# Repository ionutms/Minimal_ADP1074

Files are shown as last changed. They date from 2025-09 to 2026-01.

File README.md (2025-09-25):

# Minimal_ADP1074

## Overview

This repository contains a minimal KiCad design project for the Analog Devices ADP1074, a current mode synchronous flyback controller with iCoupler-isolated feedback. The project includes schematic designs and PCB layout files for implementing this isolated power supply controller.

## Disclaimer

> [!NOTE]
> This project is provided "as is" and without any warranty, express or implied. For more details, please see the [LICENSE](LICENSE) file.

## About the ADP1074

The ADP1074 from Analog Devices is a current mode synchronous flyback controller with integrated iCoupler technology for isolated feedback. It is designed for high-efficiency, compact isolated DC-to-DC converters.

Key features include:

- **Integrated iCoupler Technology:** Provides isolated feedback without the need for an optocoupler, improving reliability and performance.
- **Current Mode Control:** Offers excellent line and load transient response.
- **Synchronous Rectification:** Improves efficiency by replacing the secondary-side diode with a MOSFET.
- **Programmable Frequency:** The switching frequency can be adjusted to optimize for size or efficiency.
- **Protection Features:** Includes overcurrent protection (OCP), overvoltage protection (OVP), and thermal shutdown.
- **Wide Input Voltage Range:** Supports a broad range of input voltages, making it suitable for various applications.
- **Package:** Available in a 24-lead LFCSP package.

## Project Structure

```
minimal_adp1074/
├── minimal_adp1074.kicad_pro       # Project configuration file
├── minimal_adp1074.kicad_sch       # Main schematic file
├── minimal_adp1074.kicad_pcb       # PCB layout file
├── fp-lib-table                    # Footprint library table
├── sym-lib-table                   # Symbol library table
├── docs/                           # Documentation files
│   ├── bom/                        # Bill of Materials
│   │   └── minimal_adp1074_ibom.html # Interactive BOM file
│   ├── pictures/                   # Images and photos
│   │   ├── 1_minimal_adp1074_side.png
│   │   ├── 2_minimal_adp1074_top.png
│   │   ├── 3_minimal_adp1074_bottom.png
│   │   ├── 4_minimal_adp1074_left.png
│   │   └── 5_minimal_adp1074_right.png
│   └── schematics/                 # Schematic PDF exports
│       └── minimal_adp1074_schematics.pdf
└── KiCAD_Symbols_Generator/        # Submodule for symbol generation from CSV data
```

## Project Features

This design provides a minimal implementation of the ADP1074 with:

- Proper power supply connections
- Isolated feedback using integrated iCoupler technology
- Synchronous rectification for high efficiency
- Standard footprint for the 24-pin LFCSP package

## Getting Started

### Prerequisites

- [KiCad EDA](https://www.kicad.org/) version 9.0 or later installed on your system
- Git (for cloning the repository and submodule management)

### Opening the Project

1. **Clone the repository** (including submodules):
   ```bash
   git clone --recursive https://github.com/ionutms/Minimal_ADP1074.git
   ```
   
   If you've already cloned the repository without submodules, initialize them with:
   ```bash
   git submodule init
   git submodule update
   ```

2. **Open the project in KiCad**:
   - Launch KiCad
   - Click "Open Existing Project"
   - Navigate to the cloned repository folder
   - Select the `minimal_adp1074.kicad_pro` file

3. **Explore the design**:
   - Open the schematic editor to view the circuit design
   - Open the PCB editor to view the board layout
   - Review the symbol and footprint libraries used in the design

### Project Files

- **Main schematic**: `minimal_adp1074.kicad_sch` - Contains the primary circuit design with the ADP1074 and support components
- **PCB layout**: `minimal_adp1074.kicad_pcb` - Physical board design file with proper component placement
- **Project configuration**: `minimal_adp1074.kicad_pro` - KiCad project settings

## Dependencies

This project has the following dependencies:

### 1. KiCAD Symbols Generator

This repository uses [KiCAD_Symbols_Generator](https://github.com/ionutms/KiCAD_Symbols_Generator) as a submodule for custom symbol generation.

To initialize the submodule after cloning this repository:

```bash
git submodule update --init --recursive
```

### 2. 3D Models

This project requires the [3D_Models_Vault](https://github.com/ionutms/3D_Models_Vault) repository for 3D models.

#### Setup for KiCAD 9:

1. Clone the 3D models repository:
   ```bash
   git clone https://github.com/ionutms/3D_Models_Vault.git
   ```

2. In KiCAD 9, add an environment variable:
   - Variable name: `KICAD9_3D_MODELS_VAULT`
   - Variable value: Full path to where you cloned the 3D_Models_Vault repository

## Usage

After setting up the dependencies, open the project in KiCad 9 to access all features including the 3D models.

## Symbol Generator Submodule

This project includes the KiCAD_Symbols_Generator as a submodule, which provides tools for generating KiCad symbols from CSV data files. For more information on using this tool, see the [KiCAD_Symbols_Generator documentation](minimal_adp1074/KiCAD_Symbols_Generator/README.md).

## Documentation

The `docs` folder contains:
- Schematic PDF exports
- Images and photos of the design

## Visuals

The following images showcase the PCB design from different perspectives:

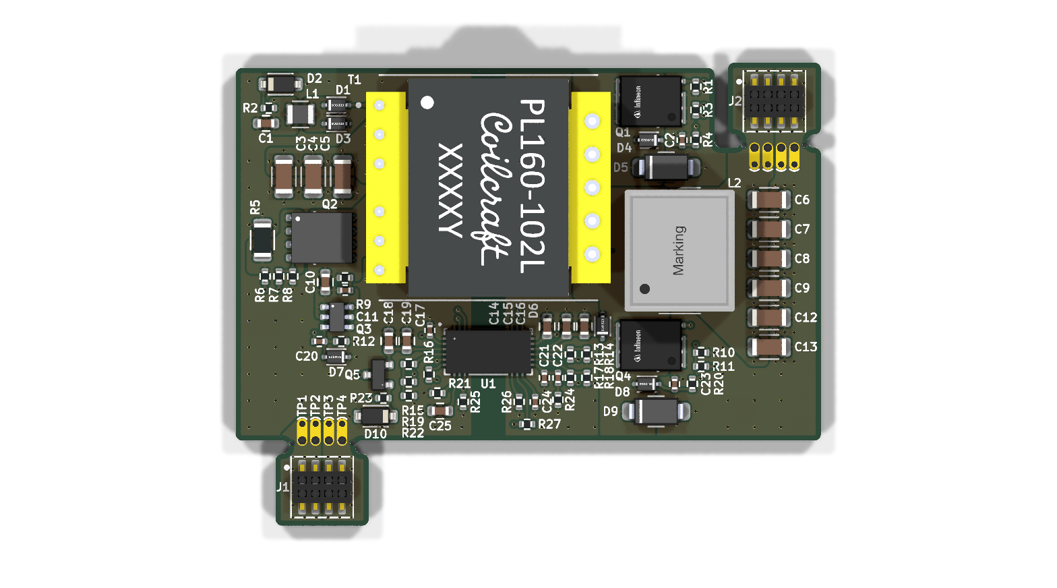
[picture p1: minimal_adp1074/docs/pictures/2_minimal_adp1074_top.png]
Top View

*Top View of the PCB*

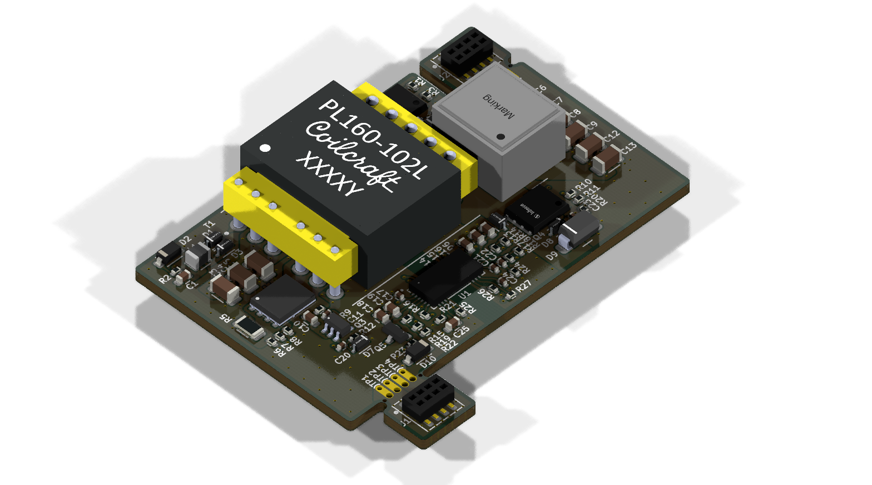
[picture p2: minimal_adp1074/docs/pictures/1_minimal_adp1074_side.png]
Side View

*Side View of the PCB*

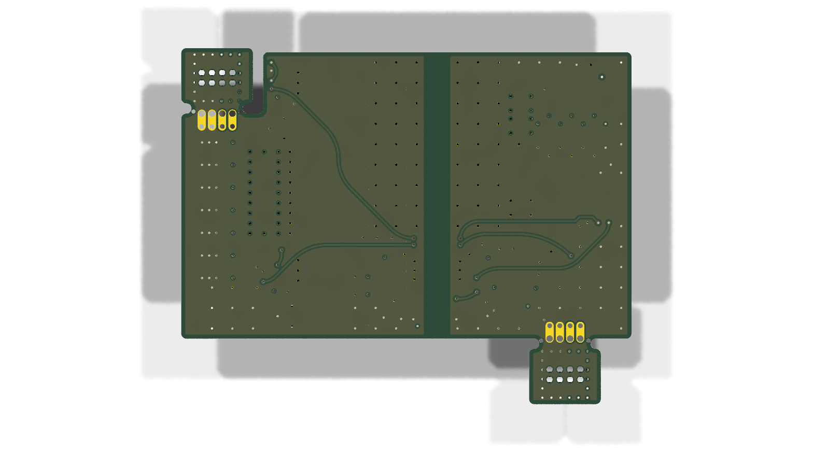
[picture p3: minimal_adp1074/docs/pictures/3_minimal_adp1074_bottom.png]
Bottom View

*Bottom View of the PCB*

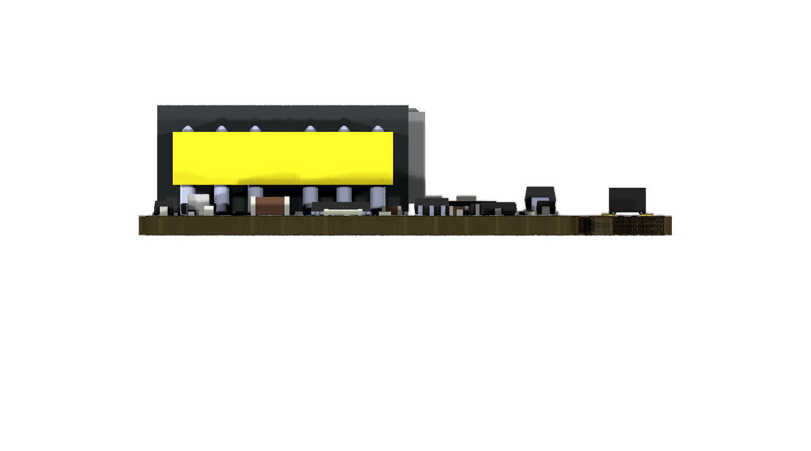
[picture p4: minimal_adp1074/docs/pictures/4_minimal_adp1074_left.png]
Left View

*Left View of the PCB*

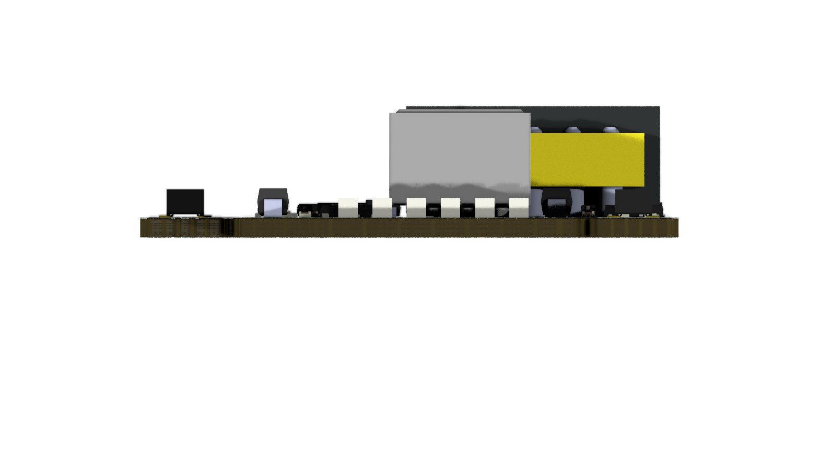
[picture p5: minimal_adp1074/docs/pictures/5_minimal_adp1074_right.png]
Right View

*Right View of the PCB*

## License

This project is licensed under the MIT License - see the [LICENSE](LICENSE) file for details.

## References

- [ADP1074 Datasheet](https://www.analog.com/media/en/technical-documentation/data-sheets/ADP1074.pdf)
- [KiCad EDA](https://www.kicad.org/)

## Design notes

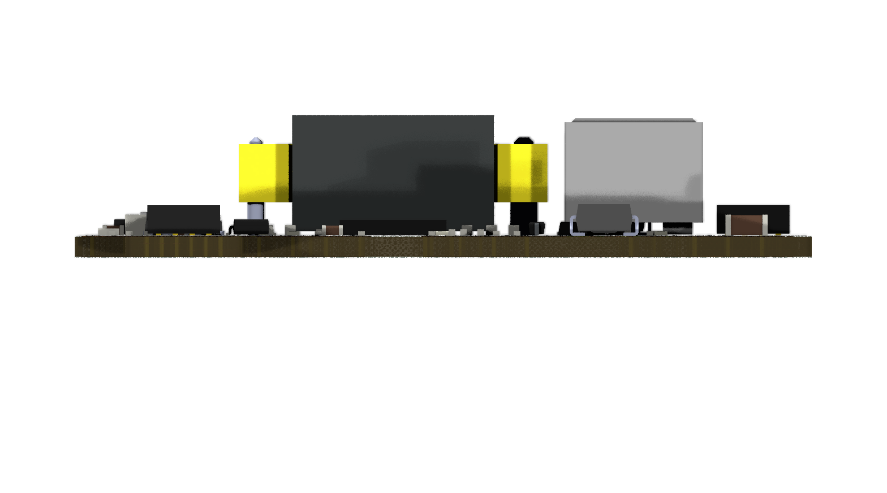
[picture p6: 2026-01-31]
minimal_adp1074/docs/pictures/6_minimal_adp1074_front.png

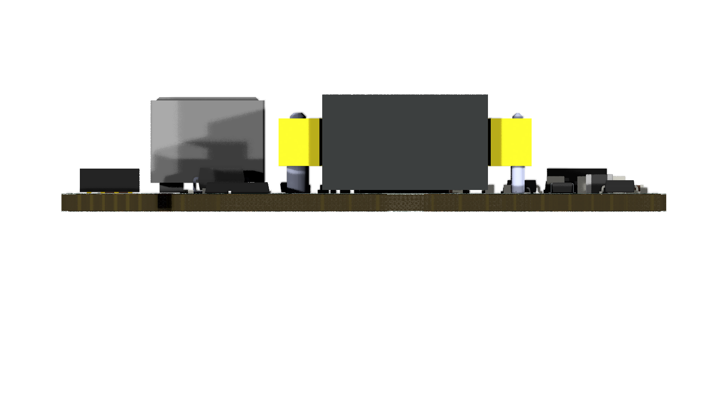
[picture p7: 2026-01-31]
minimal_adp1074/docs/pictures/7_minimal_adp1074_back.png

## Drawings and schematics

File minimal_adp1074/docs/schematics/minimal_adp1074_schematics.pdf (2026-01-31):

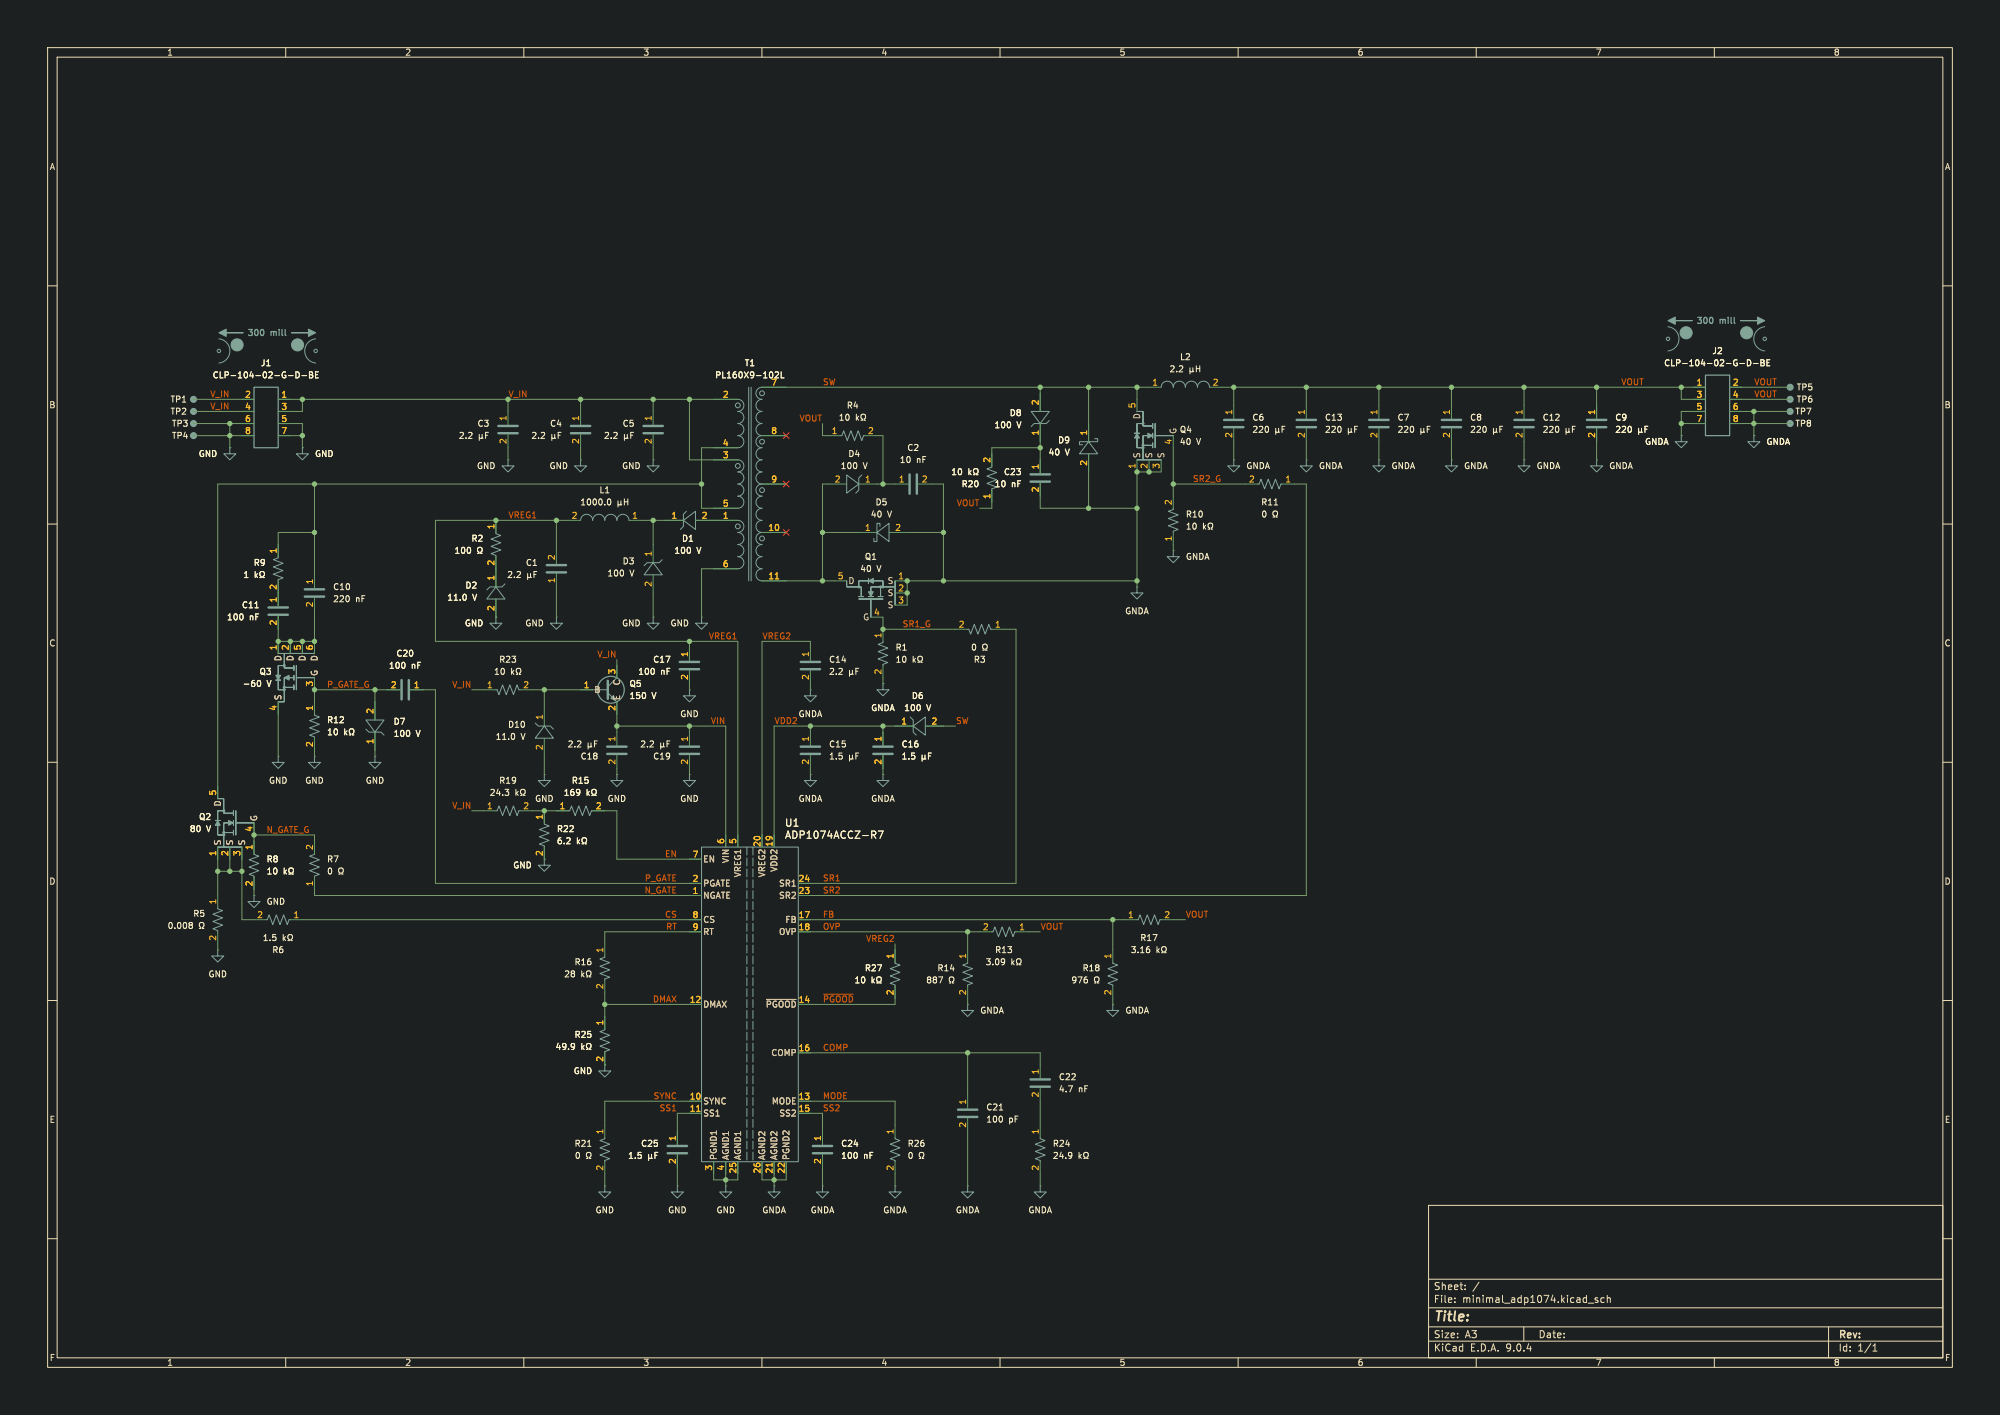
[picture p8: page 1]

5 AGND1 25 VREG2 20 AGND2 26 VDD2 19 AGND2 21 PGND2 22 SR1 24 SR2 23 FB 17 OVP 18 COMP 16 MODE 13 SS2 15 PGND1
~{PGOOD} SR1

Id: 1/1 Title: File: minimal_adp1074.kicad_sch Sheet: /

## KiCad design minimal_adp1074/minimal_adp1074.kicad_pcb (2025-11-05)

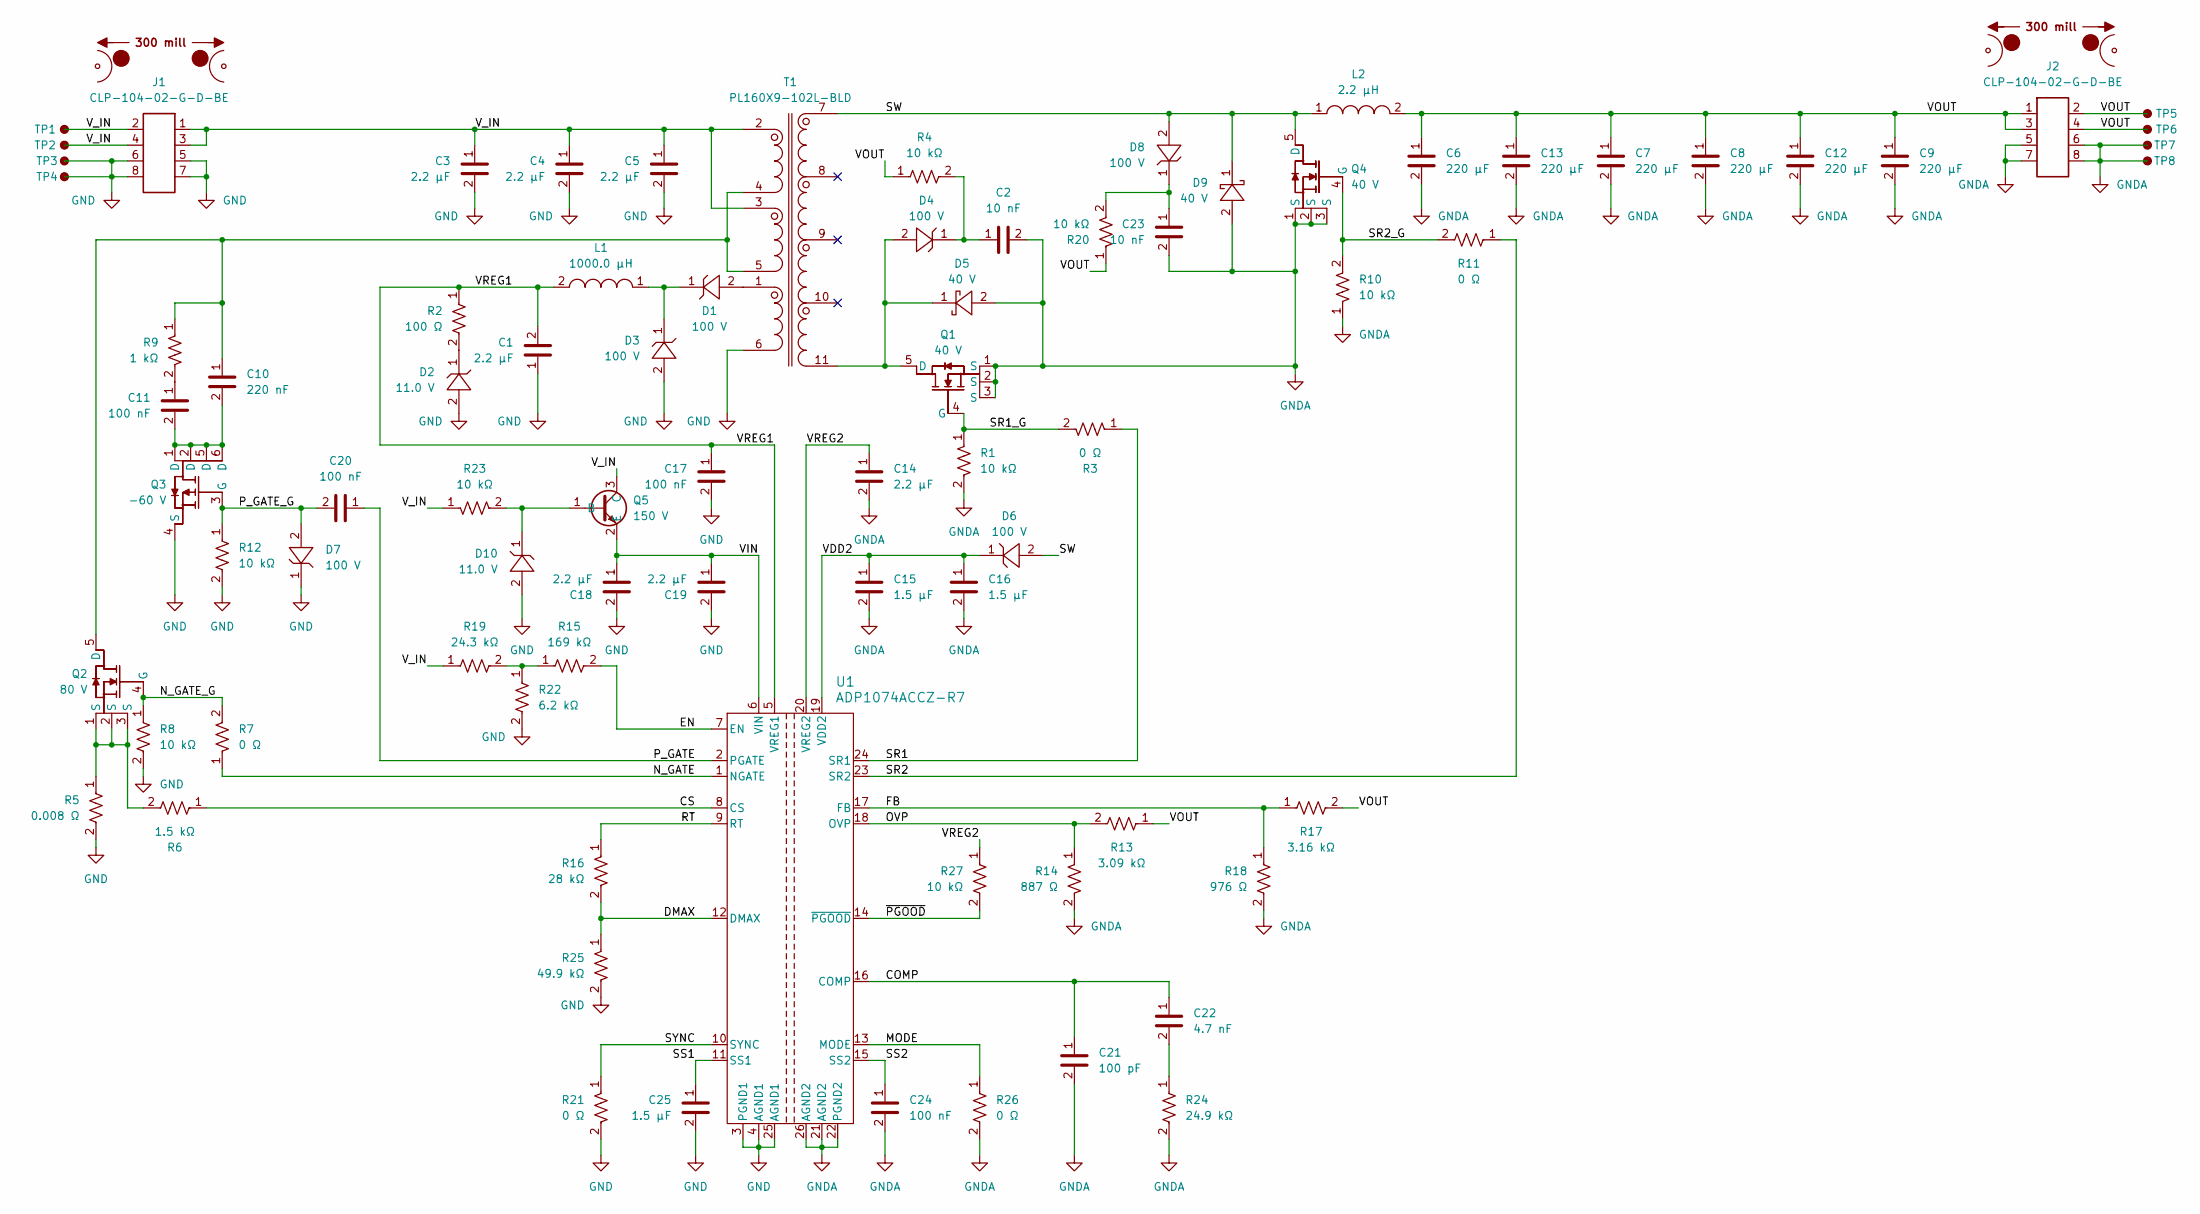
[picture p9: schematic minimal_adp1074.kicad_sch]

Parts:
C1, C14, C18, C19: 2.2 µF; C_0603_1608Metric; Tolerance 20%; Voltage Rating 35V; MPN C1005X5R1V225M050BC
C2, C23: 10 nF; C_0402_1005Metric; Tolerance 10%; Voltage Rating 50V; MPN GCM155R71H103KA55D
C3, C4, C5: 2.2 µF; C_1206_3216Metric; Tolerance 10%; Voltage Rating 50V; MPN KGM31HR71H225KU
C6, C7, C8, C9, C12, C13: 220 µF; C_1206_3216Metric; Tolerance 20%; Voltage Rating 6.3V; MPN GRM31CR60J227ME11K
C10: 220 nF; C_0603_1608Metric; Tolerance 10%; Voltage Rating 50V; MPN GCM188R71H224KA64D
C11, C17, C20, C24: 100 nF; C_0402_1005Metric; Tolerance 10%; Voltage Rating 50V; MPN GCM155R71H104KE02D
C15, C16, C25: 1.5 µF; C_0603_1608Metric; Tolerance 20%; Voltage Rating 35V; MPN C1005X5R1V155M050BC
C21: 100 pF; C_0402_1005Metric; Tolerance 1%; Voltage Rating 50V; MPN GCM1555C1H101FA16D
C22: 4.7 nF; C_0402_1005Metric; Tolerance 10%; Voltage Rating 50V; MPN GCM155R71H472KA37D
D1, D3, D4, D6, D7, D8: 100 V; SOD323; MPN 1N4148WX-TP
D2, D10: 11.0 V; SOD_123; MPN BZT52C11-7-F
D5, D9: 40 V; SMA; MPN B240A-13-F
J1, J2: CLP-104-02-G-D-BE; Current Rating (A) 5.2; Voltage Rating (V) 300; MPN CLP-104-02-G-D-BE
L1: 1000.0 µH; CB2518T; Tolerance ±10%; MPN CB2518T102K
L2: 2.2 µH; 74439369; Tolerance ±20%; MPN 74439369022
MB1, MB2: mouse-bite-50mil-300mil
Q1, Q4: 40 V; TDSON-8 FL; MPN BSC014N04LSI
Q2: 80 V; PowerPAK SO-8 Single; MPN SIR680DP-T1-RE3
Q3: -60 V; SOT-26; MPN ZXMP6A17E6TA
Q5: 150 V; SOT23-3; MPN FMMT625TA
R1, R4, R8, R10, R12, R20, R23, R27: 10 kΩ; R_0402_1005Metric; Tolerance 1%; Voltage Rating 50V; MPN ERJ-2RKF1002X
R2: 100 Ω; R_0402_1005Metric; Tolerance 1%; Voltage Rating 50V; MPN ERJ-2RKF1000X
R3, R7, R11, R21, R26: 0 Ω; R_0402_1005Metric; Tolerance 5%; Voltage Rating 50V; MPN ERJ-2GE0R00X
R5: 0.008 Ω; R_1206_3216Metric; Tolerance 1%; Voltage Rating 200V; MPN PMR18EZPFU8L00
R6: 1.5 kΩ; R_0402_1005Metric; Tolerance 1%; Voltage Rating 50V; MPN ERJ-2RKF1501X
R9: 1 kΩ; R_0402_1005Metric; Tolerance 1%; Voltage Rating 50V; MPN ERJ-2RKF1001X
R13: 3.09 kΩ; R_0402_1005Metric; Tolerance 1%; Voltage Rating 50V; MPN ERJ-2RKF3091X
R14: 887 Ω; R_0402_1005Metric; Tolerance 1%; Voltage Rating 50V; MPN ERJ-2RKF8870X
R15: 169 kΩ; R_0402_1005Metric; Tolerance 1%; Voltage Rating 50V; MPN ERJ-2RKF1693X
R16: 28 kΩ; R_0402_1005Metric; Tolerance 1%; Voltage Rating 50V; MPN ERJ-2RKF2802X
R17: 3.16 kΩ; R_0402_1005Metric; Tolerance 1%; Voltage Rating 50V; MPN ERJ-2RKF3161X
R18: 976 Ω; R_0402_1005Metric; Tolerance 1%; Voltage Rating 50V; MPN ERJ-2RKF9760X
R19: 24.3 kΩ; R_0402_1005Metric; Tolerance 1%; Voltage Rating 50V; MPN ERJ-2RKF2432X
R22: 6.2 kΩ; R_0402_1005Metric; Tolerance 1%; Voltage Rating 50V; MPN ERJ-2RKF6201X
R24: 24.9 kΩ; R_0402_1005Metric; Tolerance 1%; Voltage Rating 50V; MPN ERJ-2RKF2492X
R25: 49.9 kΩ; R_0402_1005Metric; Tolerance 1%; Voltage Rating 50V; MPN ERJ-2RKF4992X
T1: PL160X9-102L-BLD; PL160X9-102L; Tolerance ±10%; MPN PL160X9-102L-BLD
TP1, TP2, TP3, TP4, TP5, TP6, TP7, TP8: TestPoint; TestPoint_THTPad_Castelated
U1: ADP1074ACCZ-R7; CC-24-6_ADI; MPN ADP1074ACCZ-R7

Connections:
/COMP: C21.1, C22.1, U1.16 (COMP)
/CS: R6.1, U1.8 (CS)
/DMAX: R16.2, R25.1, U1.12 (DMAX)
/EN: R15.2, U1.7 (EN)
/FB: R17.1, R18.1, U1.17 (FB)
/MODE: R26.1, U1.13 (MODE)
/N_GATE: R7.1, U1.1 (NGATE)
/N_GATE_G: Q2.4 (G), R7.2, R8.1
/OVP: R13.2, R14.1, U1.18 (OVP)
/P_GATE: C20.1, U1.2 (PGATE)
/P_GATE_G: C20.2, D7.2, Q3.3 (G), R12.1
/RT: R16.1, U1.9 (RT)
/SR1: R3.1, U1.24 (SR1)
/SR1_G: Q1.4 (G), R1.1, R3.2
/SR2: R11.1, U1.23 (SR2)
/SR2_G: Q4.4 (G), R10.2, R11.2
/SS1: C25.1, U1.11 (SS1)
/SS2: C24.1, U1.15 (SS2)
/SW: D6.2, D8.2, D9.1, L2.1, Q4.5 (D), T1.7
/SYNC: R21.1, U1.10 (SYNC)
/VDD2: C15.1, C16.1, D6.1, U1.19 (VDD2)
/VIN: C18.1, C19.1, Q5.2 (E), U1.6 (VIN)
/VOUT: C6.1, C7.1, C8.1, C9.1, C12.1, C13.1, J2.1, J2.2, J2.3, J2.4, L2.2, R4.1, R13.1, R17.2, R20.1, TP5.1, TP6.1
/VREG1: C1.2, C17.1, L1.2, R2.1, U1.5 (VREG1)
/VREG2: C14.1, R27.1, U1.20 (VREG2)
/V_IN: C3.1, C4.1, C5.1, J1.1, J1.2, J1.3, J1.4, Q5.3 (C), R19.1, R23.1, T1.2, T1.3, TP1.1, TP2.1
/~PGOOD: R27.2, U1.14 (~PGOOD)
GND: C1.1, C3.2, C4.2, C5.2, C17.2, C18.2, C19.2, C25.2, D2.2, D3.2, D7.1, D10.2, J1.5, J1.6, J1.7, J1.8, Q3.4 (S), R5.2, R8.2, R12.2, R21.2, R22.2, R25.2, T1.6, TP3.1, TP4.1, U1.3 (PGND1), U1.4 (AGND1), U1.25 (AGND1)
GNDA: C2.2, C6.2, C7.2, C8.2, C9.2, C12.2, C13.2, C14.2, C15.2, C16.2, C21.2, C23.2, C24.2, D5.2, D9.2, J2.5, J2.6, J2.7, J2.8, Q1.1 (S), Q1.2 (S), Q1.3 (S), Q4.1 (S), Q4.2 (S), Q4.3 (S), R1.2, R10.1, R14.2, R18.2, R24.2, R26.2, TP7.1, TP8.1, U1.21 (AGND2), U1.22 (PGND2), U1.26 (AGND2)
unnamed: C2.1, D4.1, R4.2
unnamed: C10.2, C11.2, Q3.1 (D), Q3.2 (D), Q3.5 (D), Q3.6 (D)
unnamed: C11.1, R9.2
unnamed: C22.2, R24.1
unnamed: C23.1, D8.1, R20.2
unnamed: D1.1, D3.1, L1.1
unnamed: D1.2, T1.1
unnamed: D2.1, R2.2
unnamed: D4.2, D5.1, Q1.5 (D), T1.11
unnamed: C10.1, Q2.5 (D), R9.1, T1.4, T1.5
unnamed: Q2.1 (S), Q2.2 (S), Q2.3 (S), R5.1, R6.2
unnamed: D10.1, Q5.1 (B), R23.2
unnamed: R15.1, R19.2, R22.1

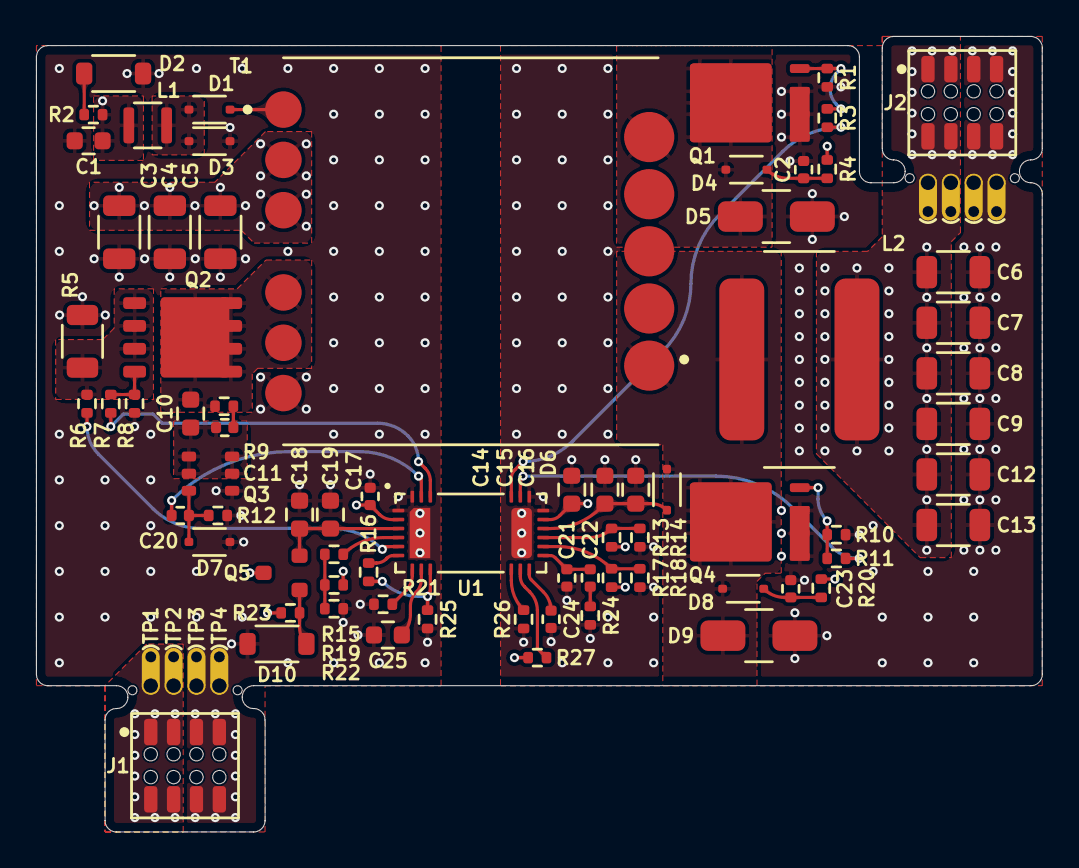
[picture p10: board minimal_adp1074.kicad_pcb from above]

Board: 4 copper layers, 55.9 x 44.2 mm, 83 parts (0 on the bottom side), 42 nets.

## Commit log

2025-09-21 Add KiCAD project files and submodule for symbol generation
    [minimal_adp1074.kicad_pcb, minimal_adp1074.kicad_sch]
2025-09-21 Add GitHub Actions workflows for KiCad documentation and 3D model generation
2025-09-21 Update KiCad documentation for minimal_adp1074 (schematics and PCB renders)
2025-09-21 Update KiCAD view settings to 1:1 zoom ratio and center views
2025-10-12 chore: update workflows and kicad config from central repository
